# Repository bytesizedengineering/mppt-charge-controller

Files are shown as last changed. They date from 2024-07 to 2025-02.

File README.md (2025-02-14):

## License  
This project is licensed under the GNU General Public License v3.0 - see the [LICENSE](LICENSE) file for details.

# mppt charge controller
BQ 24650 datasheet can be found here https://www.ti.com/general/docs/suppproductinfo.tsp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

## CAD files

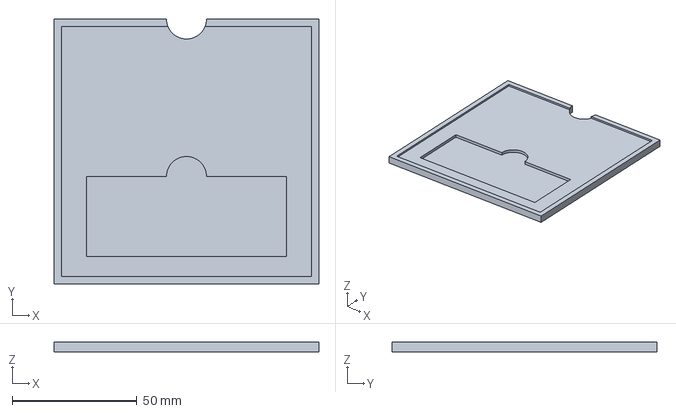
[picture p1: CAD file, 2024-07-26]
Electrical Design/Solder Paste Jig.3mf
106.0 x 106.0 x 4.00 mm

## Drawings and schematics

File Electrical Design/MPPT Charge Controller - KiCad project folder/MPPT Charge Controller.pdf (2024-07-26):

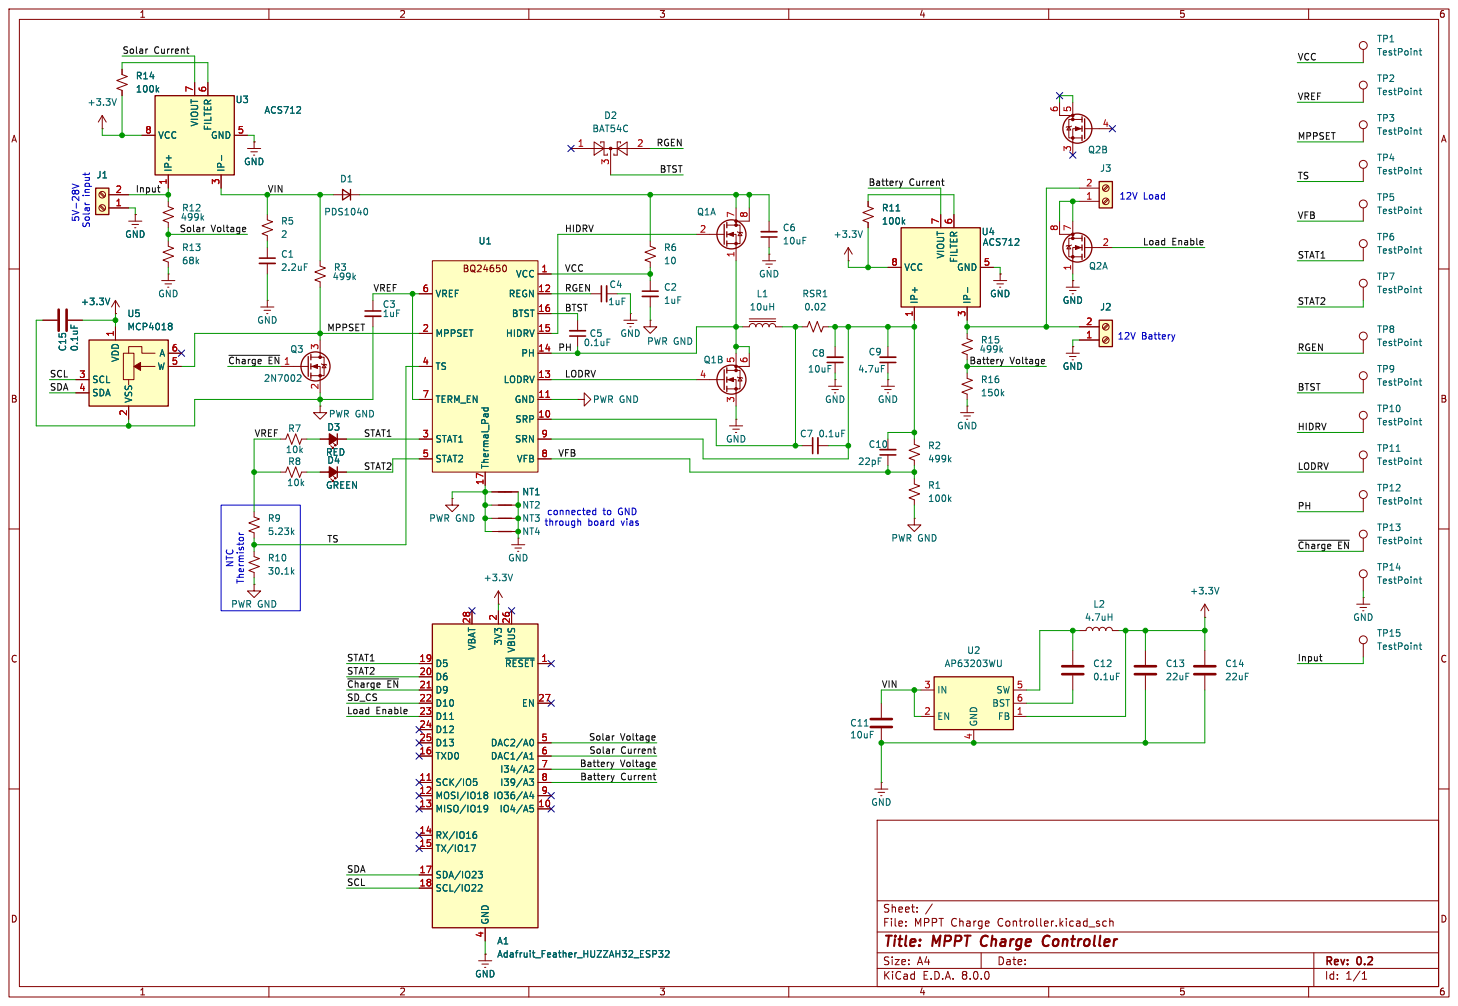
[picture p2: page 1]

STAT1 VCC
~{Charge EN} TSMPPSET BTST PH

7 VCC 8 NT1 U1Thermal_Pad 17 VCC 1 SRP 10 GND 11 REGN 12

TP12 TestPoint TP10 TestPoint TP13 TestPoint TP15 TestPoint D4 GREEN

2 D6 20 D9 21 D10 22 D11 23 D12 24 D13 25 VBUS 26 EN 27 VBAT 28 GND

Battery Current Solar Current STAT1 SD_CS

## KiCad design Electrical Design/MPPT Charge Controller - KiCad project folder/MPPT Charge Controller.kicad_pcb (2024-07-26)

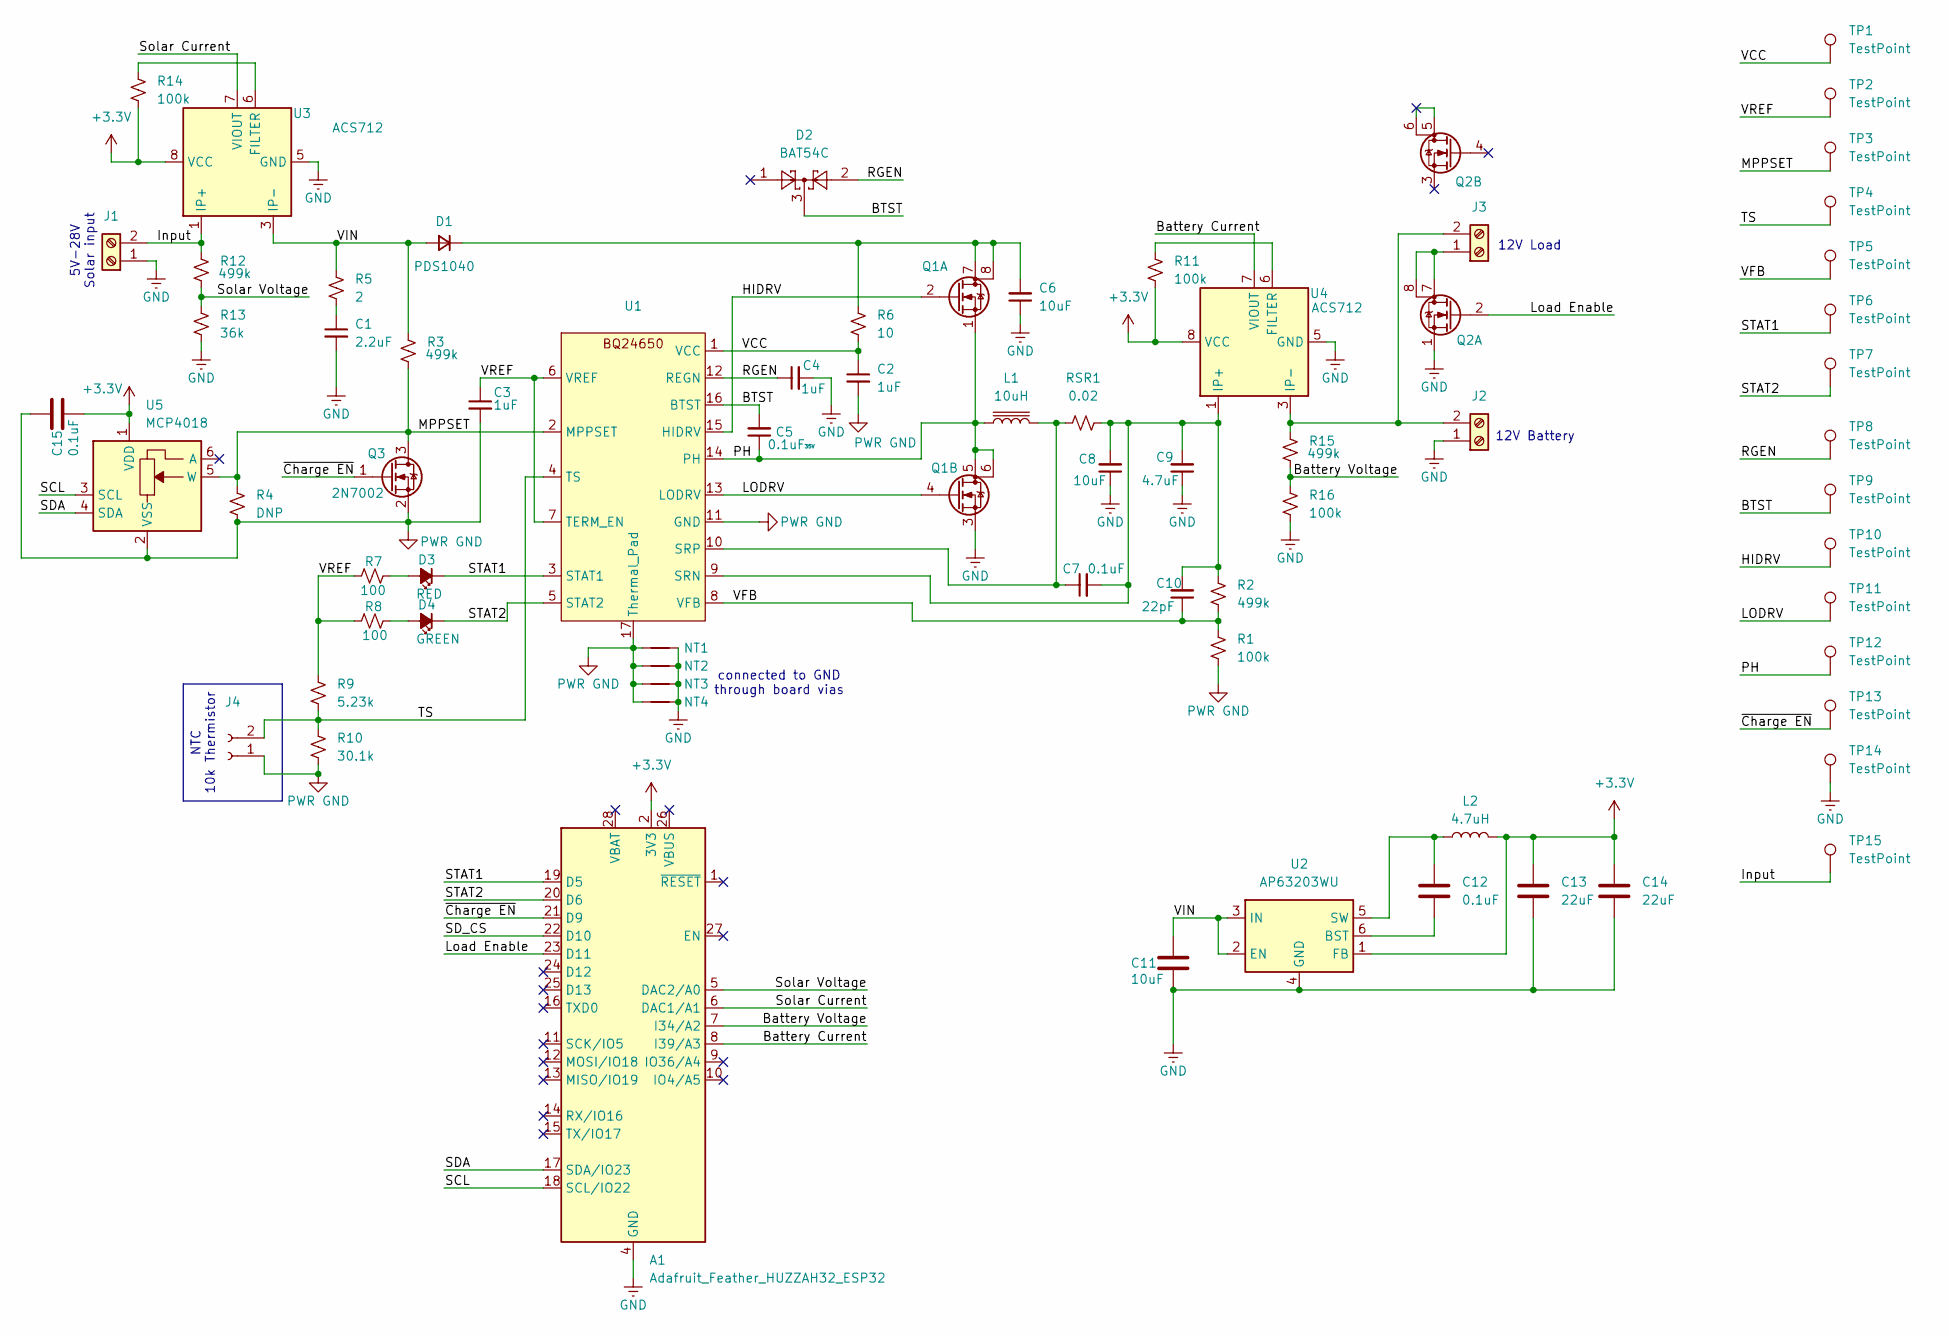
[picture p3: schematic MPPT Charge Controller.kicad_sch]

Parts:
A1: Adafruit_Feather_HUZZAH32_ESP32; Adafruit_Feather
C1: 2.2uF; C_1210_3225Metric
C2, C3, C4: 1uF; C_0603_1608Metric
C5: 0.1uF; C_0603_1608Metric; Voltage Rating 35V
C6, C8: 10uF; C_1206_3216Metric
C7, C12, C15: 0.1uF; C_0603_1608Metric
C9: 4.7uF; C_0805_2012Metric
C10: 22pF; C_0603_1608Metric
C11: 10uF; C_0603_1608Metric
C13, C14: 22uF; C_0603_1608Metric
D1: PDS1040; D_PowerDI-5
D2: BAT54C; SOT-23
D3: RED; LED_0603_1608Metric
D4: GREEN; LED_0603_1608Metric
J1, J2, J3: Conn_01x02_Socket; TerminalBlock_bornier-2_P5.08mm
J4: PinSocket_1x02_P2.54mm_Vertical
L1: 10uH; L_Vishay_6.9x6.5
L2: 4.7uH; L_Vishay_IFSC-1515AH_4x4x1.8mm
NT1, NT2, NT3, NT4: NetTie-2_SMD_Pad0.5mm
Q1, Q2: Q_Dual_NMOS_S1G1S2G2D2D2D1D1; PowerPAK_SO-8_Dual
Q3: 2N7002; SOT-23
R1, R11, R14, R16: 100k; R_0603_1608Metric
R2, R3, R12, R15: 499k; R_0603_1608Metric
R4: DNP; R_0603_1608Metric
R5: 2; R_2512_6332Metric
R6: 10; R_0603_1608Metric
R7, R8: 100; R_0603_1608Metric
R9: 5.23k; R_0603_1608Metric
R10: 30.1k; R_0603_1608Metric
R13: 36k; R_0603_1608Metric
RSR1: 0.02; R_1206_3216Metric
TP1, TP2, TP3, TP4, TP5, TP6, TP7, TP8, TP9, TP10, TP11, TP12, TP13: TestPoint; TestPoint_Pad_D1.0mm
TP14, TP15: TestPoint; TestPoint_Loop_D2.60mm_Drill1.6mm_Beaded
U1: VQFN-16_EP_3.5x3.5_Pitch0.5mm
U2: AP63203WU; TSOT-23-6
U3, U4: ACS712; SOIC-8_3.9x4.9mm_P1.27mm
U5: MCP4018; SOT-363_SC-70-6

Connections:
+3.3V: A1.2 (3V3), C13.1, C14.1, C15.1, L2.2, R11.2, R14.2, U2.1 (FB), U3.8 (VCC), U4.8 (VCC), U5.1 (VDD)
/BTST: C5.2, D2.3, TP9.1, U1.16 (BTST)
/Battery Current: A1.8 (I39/A3), U4.7 (VIOUT)
/Battery Voltage: A1.7 (I34/A2), R15.2, R16.1
/HIDRV: Q1.2 (G), TP10.1, U1.15 (HIDRV)
/Input: J1.2, R12.1, TP15.1, U3.1 (IP+), U3.2 (IP+)
/LODRV: Q1.4 (G), TP11.1, U1.13 (LODRV)
/Load Enable: A1.23 (D11), Q2.2 (G)
/MPPSET: Q3.3 (D), R3.2, R4.1, TP3.1, U1.2 (MPPSET), U5.5 (W)
/PH: C5.1, L1.1, Q1.1 (S), Q1.5 (D), Q1.6 (D), TP12.1, U1.14 (PH)
/RGEN: C4.1, D2.2, TP8.1, U1.12 (REGN)
/SCL: A1.18 (SCL/IO22), U5.3 (SCL)
/SDA: A1.17 (SDA/IO23), U5.4 (SDA)
/SD_CS: A1.22 (D10)
/STAT1: A1.19 (D5), D3.1 (K), TP6.1, U1.3 (STAT1)
/STAT2: A1.20 (D6), D4.1 (K), TP7.1, U1.5 (STAT2)
/Solar Current: A1.6 (DAC1/A1), U3.7 (VIOUT)
/Solar Voltage: A1.5 (DAC2/A0), R12.2, R13.1
/TS: J4.2, R9.2, R10.1, TP4.1, U1.4 (TS)
/VCC: C2.1, R6.2, TP1.1, U1.1 (VCC)
/VFB: C10.1, R1.1, R2.2, TP5.1, U1.8 (VFB)
/VIN: C11.2, D1.2 (A), R3.1, R5.1, U2.2 (EN), U2.3 (IN), U3.3 (IP-), U3.4 (IP-)
/VREF: C3.1, R7.1, R8.1, R9.1, TP2.1, U1.6 (VREF), U1.7 (TERM_EN)
/~Charge EN: A1.21 (D9), Q3.1 (G), TP13.1
GND: A1.4 (GND), C1.2, C4.2, C6.1, C8.1, C9.1, C11.1, C13.2, C14.2, J1.1, J2.1, NT1.2, NT2.2, NT3.2, NT4.2, Q1.3 (S), Q2.1 (S), R13.2, R16.2, TP14.1, U2.4 (GND), U3.5 (GND), U4.5 (GND)
unnamed: C1.1, R5.2
unnamed: C6.2, D1.1 (K), Q1.7 (D), Q1.8 (D), R6.1
unnamed: D3.2 (A), R7.2
unnamed: D4.2 (A), R8.2
unnamed: J2.2, J3.2, R15.1, U4.3 (IP-), U4.4 (IP-)
unnamed: J3.1, Q2.7 (D), Q2.8 (D)
unnamed: C7.2, C8.2, C9.2, C10.2, R2.1, RSR1.1, U1.9 (SRN), U4.1 (IP+), U4.2 (IP+)
unnamed: C7.1, L1.2, RSR1.2, U1.10 (SRP)
unnamed: C12.2, U2.6 (BST)
unnamed: C12.1, L2.1, U2.5 (SW)
unnamed: R14.1, U3.6 (FILTER)
unnamed: R11.1, U4.6 (FILTER)
PWR GND: C2.2, C3.2, C15.2, J4.1, NT1.1, NT2.1, NT3.1, NT4.1, Q3.2 (S), R1.2, R4.2, R10.2, U1.11 (GND), U1.17 (Thermal_Pad), U5.2 (VSS)

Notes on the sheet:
NTC 10k Thermistor
5V-28V Solar input
12V Load
12V Battery
connected to GND through board vias

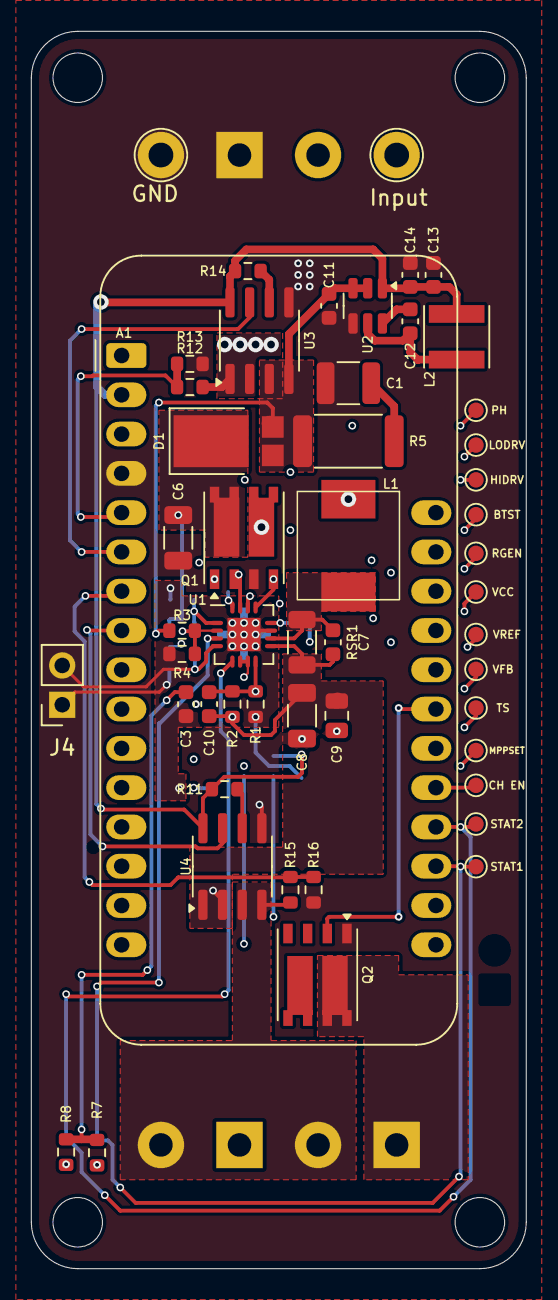
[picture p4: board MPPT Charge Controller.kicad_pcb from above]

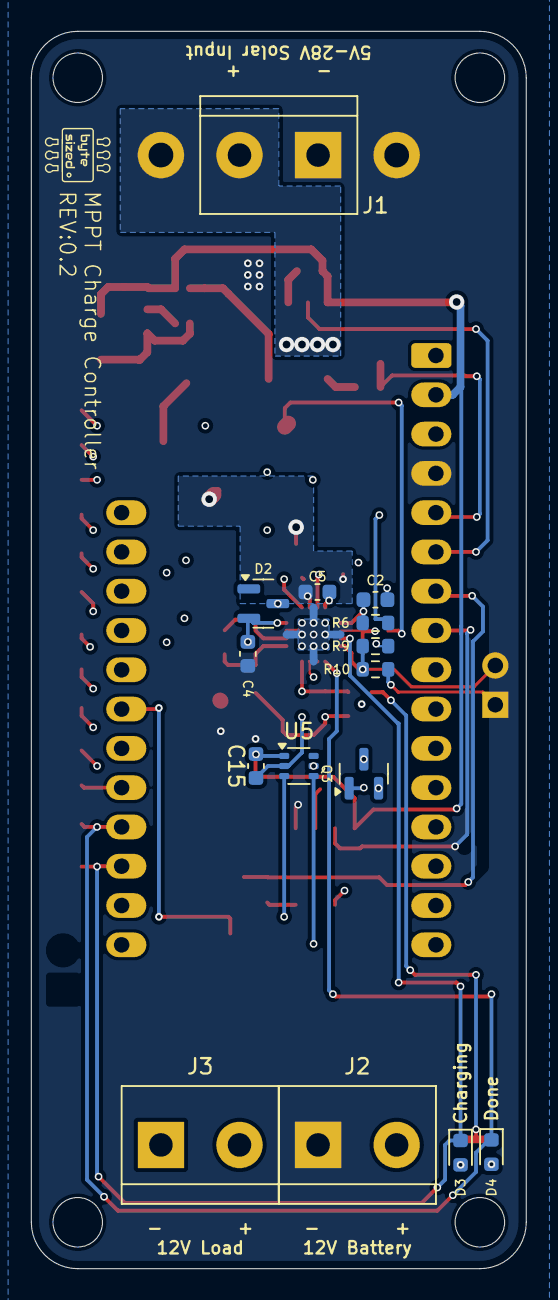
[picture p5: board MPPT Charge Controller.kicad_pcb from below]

Board: 4 copper layers, 32.0 x 80.0 mm, 70 parts (19 on the bottom side), 37 nets.

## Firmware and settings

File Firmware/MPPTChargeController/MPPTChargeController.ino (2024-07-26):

#define LOAD_ENABLE_BUTTON 0 // pulled high by default
#define BATTERY_INFO_BUTTON 1 // pulled low by default
#define SOLAR_INFO_BUTTON 2 // pulled low by default
#define CHARGING_STATUS 5
#define COMPLETE_STATUS 6
#define CHARGE_EN 9
#define LOAD_EN 11
#define SOLAR_VOLTAGE_ADC A0
#define SOLAR_CURRENT_ADC A1
#define BATTERY_VOLTAGE_ADC A2
#define BATTERY_CURRENT_ADC A3
#define MCP4018_ADDRESS 0x2F
#define UPDATE_DATA_INTERVAL 1000

#include <SPI.h>
#include <Wire.h>
#include <Adafruit_GFX.h>    // Core graphics library
#include <Adafruit_ST7789.h> // Hardware-specific library for ST7789
#include <Fonts/FreeSansBold18pt7b.h>
#include <Fonts/FreeSansBold12pt7b.h>


// TFT display and button variables
Adafruit_ST7789 tft = Adafruit_ST7789(TFT_CS, TFT_DC, TFT_RST);
const int displayWidth = 240;
const int displayHeight = 135;
bool solarInfoButtonWasPressed = true, batteryInfoButtonWasPressed = false, loadEnableButtonWasPressed = false, newHeader = true;
unsigned long lastTimeSolarInfoButtonWasPressed = 0, lastTimeBatteryInfoButtonWasPressed = 0, lastTimeLoadEnableButtonWasPressed = 0;
float solarVoltage = 0.0, previousSolarVoltage = 0.0, solarCurrent = 0.0, previousSolarCurrent = 0.0, solarPower = 0.0, previousSolarPower = 0.0;
float batteryVoltage = 0.0, previousBatteryVoltage = 0.0, batteryCurrent = 0.0, previousBatteryCurrent = 0.0, batteryPower = 0.0;
unsigned long lastTimeSolarWasDisplayed = 0, lastTimeBatteryWasDisplayed = 0, lastTimeStatsWerePrinted = 0;
bool increaseVmp = true;

uint8_t potValue = 96;

// Interrupt Service Routines
void IRAM_ATTR loadEnableButton(){
  if(millis() - lastTimeLoadEnableButtonWasPressed > 250){
    lastTimeLoadEnableButtonWasPressed = millis();
    solarInfoButtonWasPressed = false;
    batteryInfoButtonWasPressed = false;
    loadEnableButtonWasPressed = true;
    newHeader = true;
    //Serial.println("load enable button was pressed.");
  }
}
void IRAM_ATTR batteryInfoButton(){
  if(millis() - lastTimeBatteryInfoButtonWasPressed > 250){
    lastTimeBatteryInfoButtonWasPressed = millis();
    solarInfoButtonWasPressed = false;
    batteryInfoButtonWasPressed = true;
    loadEnableButtonWasPressed = false;
    newHeader = true;
    //Serial.println("battery info button was pressed.");
  }
}
void IRAM_ATTR solarInfoButton(){
  if(millis() - lastTimeSolarInfoButtonWasPressed > 250){
    lastTimeSolarInfoButtonWasPressed = millis();
    solarInfoButtonWasPressed = true;
    batteryInfoButtonWasPressed = false;
    loadEnableButtonWasPressed = false;
    newHeader = true;
    //Serial.println("solar info button was pressed.");
  }
}

void setup() {
  Serial.begin(115200);
  Wire.begin();
  // Initialize buttons
  pinMode(LOAD_ENABLE_BUTTON, INPUT_PULLUP);
  pinMode(BATTERY_INFO_BUTTON, INPUT_PULLDOWN);
  pinMode(SOLAR_INFO_BUTTON, INPUT_PULLDOWN);


  attachInterrupt(digitalPinToInterrupt(LOAD_ENABLE_BUTTON), loadEnableButton, FALLING);
  attachInterrupt(digitalPinToInterrupt(BATTERY_INFO_BUTTON), batteryInfoButton, RISING);
  attachInterrupt(digitalPinToInterrupt(SOLAR_INFO_BUTTON), solarInfoButton, RISING);

  // Initialize TFT
  pinMode(TFT_BACKLITE, OUTPUT);
  digitalWrite(TFT_BACKLITE, HIGH);
  pinMode(TFT_I2C_POWER,OUTPUT);
  digitalWrite(TFT_I2C_POWER, HIGH);
  delay(10);
  tft.init(displayHeight, displayWidth); // Init ST7789 240x135
  tft.setRotation(1);
  tft.fillScreen(ST77XX_BLACK);
  //tft.println("Solar MPPT\n Charge Controller "); delay(5000); tft.fillScreen(ST77XX_BLACK);

  pinMode(CHARGING_STATUS, INPUT);
  pinMode(COMPLETE_STATUS, INPUT);
  pinMode(CHARGE_EN, OUTPUT); digitalWrite(CHARGE_EN, LOW);
  pinMode(LOAD_EN, OUTPUT); digitalWrite(LOAD_EN, HIGH);





}

void loop() {
  //read solar voltage and current, and calculate power
  unsigned long sum = 0;
  int sample = 0, numSamples = 100;
  for(int i=0; i<numSamples; i++){
    sample = analogReadMilliVolts(SOLAR_VOLTAGE_ADC);
    sum += sample;
    delay(10);
  }
  float averageSample = sum/numSamples;
  solarVoltage = averageSample*535/36.0/1000.0 + 0.5; // voltage divider resistor values on solar input
  //solarVoltage = previousSolarVoltage*0.99 + solarVoltage*0.01;
  //previousSolarVoltage = solarVoltage;

  sum = 0;
  for(int i=0; i<numSamples; i++){
    sample = analogReadMilliVolts(SOLAR_CURRENT_ADC);
    sum += sample;
    delay(10);
  }
  averageSample = sum/numSamples;
  solarCurrent = (averageSample-1650)/132.0-0.06; // sensitivity is 132mV/A. When no curernt is flowing, sensor outputs 3.3V/2
  //solarCurrent = previousSolarCurrent*0.99 + solarCurrent*0.01;
  //previousSolarCurrent = solarCurrent;

  solarPower = solarVoltage*solarCurrent;
  setVmp();
  previousSolarPower = solarPower;

  //read battery voltage and current and calculate power
  sum = 0;

  batteryVoltage = (analogReadMilliVolts(BATTERY_VOLTAGE_ADC)*599/100.0)/1000.0 + 0.4; // voltage divider resistor values on battery output
  batteryVoltage = previousBatteryVoltage*0.99 + batteryVoltage*0.01;
  previousBatteryVoltage = batteryVoltage;

  batteryCurrent = (analogReadMilliVolts(BATTERY_CURRENT_ADC)*10000/3300.0-5000)/1000.0; // Using a +/-10A current sensor running on 3.3V VCC
  batteryCurrent = previousBatteryCurrent*0.95 + batteryCurrent*0.05;
  previousBatteryCurrent = batteryCurrent;

  batteryPower = batteryVoltage*batteryCurrent;

  float controllerEfficiency = batteryPower/solarPower;


  if(millis() - lastTimeStatsWerePrinted > UPDATE_DATA_INTERVAL){
    lastTimeStatsWerePrinted = millis();
    Serial.print("Solar Input: ");
    Serial.print(solarVoltage); Serial.print("V\t");
    Serial.print(solarCurrent); Serial.print("A\t");
    Serial.print(solarPower); Serial.print("W\t");
    Serial.print("Battery Output: ");
    Serial.print(batteryVoltage); Serial.print("V\t");
    Serial.print(batteryCurrent); Serial.print("A\t");
    Serial.print(batteryPower); Serial.print("W\t");
    Serial.print("Controller Effeciency: "); Serial.print(controllerEfficiency*100); Serial.println("%");


  }

  if(loadEnableButtonWasPressed){
    if(newHeader){
      displayHeader(ST77XX_GREEN, "load enable");
      newHeader = false;
    }
  }
  if(batteryInfoButtonWasPressed){
    if(newHeader){
      displayHeader(ST77XX_RED, "Battery Output");
      newHeader = false;
    }
    if(millis() - lastTimeBatteryWasDisplayed > UPDATE_DATA_INTERVAL){
      lastTimeBatteryWasDisplayed = millis();
      displayData("battery");
    }
  }
  if(solarInfoButtonWasPressed){
    if(newHeader){
      displayHeader(ST77XX_YELLOW, "Solar Input");
      newHeader = false;
    }
    if(millis() - lastTimeSolarWasDisplayed > UPDATE_DATA_INTERVAL){
      lastTimeSolarWasDisplayed = millis();
      displayData("solar");
    }
  }
}

void displayHeader(uint16_t color, String headerText){
  tft.fillRect(0,0,displayWidth,displayHeight/3 - 1,color);
  tft.setTextColor(ST77XX_BLACK); tft.setFont(&FreeSansBold12pt7b);
  tft.setCursor(0, 30);
  tft.print(headerText);
}

void displayData(String source){
  tft.fillRect(0,displayHeight/3,displayWidth,displayHeight*2/3,ST77XX_BLACK);
  tft.setTextColor(ST77XX_WHITE); tft.setFont(&FreeSansBold18pt7b);
  tft.setCursor(0, 75);
  if(source == "solar"){
    tft.print(solarVoltage); tft.print("V  ");
    tft.print(solarCurrent); tft.println("A");
    tft.print(solarPower);   tft.print("W  ");
  }
  else if(source == "battery"){
    tft.print(batteryVoltage); tft.print("V  ");
    tft.print(batteryCurrent); tft.println("A");
    tft.print(batteryPower);   tft.print("W  ");
  }
  else{
    tft.println("invalid data source");
  }
  tft.println(potValue);
}

void setPotentiometerValue(uint8_t value) {
  Wire.beginTransmission(MCP4018_ADDRESS);
  Wire.write(value); //50k digital potentiometer, with 128 taps.
  Wire.endTransmission();
}


void setVmp(){
  // Decreasing the potValue will increase the Vmp.
  // Higher potValue -> lower Vmp. Lower potValue -> higher Vmp.
  // For potValue of 127 (50k Ohms), the Vmp = 13.2V.
  // For potValue of 64 (25k Ohms), Vmp = 25.2V.

  if(solarPower > previousSolarPower){
    if(increaseVmp) potValue--;
    else potValue++;
  }
  else{
    if(increaseVmp){
      increaseVmp = false;
      potValue++;
    }
    else{
      increaseVmp = true;
      potValue--;
    }
  }
  potValue = constrain(potValue, 64, 127); // potValues less than 64 continue to increase Vmp and are unusable for this design. For example a potValue of 1 (391 Ohms), the Vmp would be 1,536.6V
  setPotentiometerValue(potValue);
}

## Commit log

2024-04-19 Created KiCad project
    [MPPT Charge Controller.kicad_pcb, MPPT Charge Controller.kicad_sch]
2024-05-01 Created BQ24650 symbol and footprint
    [MPPT Charge Controller.kicad_pcb, MPPT Charge Controller.kicad_sch]
2024-05-09 Added circuitry to schematic
    [MPPT Charge Controller.kicad_sch]
2024-05-28 Rev .01
    [MPPT Charge Controller-B_Cu.gbr, MPPT Charge Controller-B_Fab.gbr, MPPT Charge Controller-B_Mask.gbr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]
2024-07-08 fixed R4 inconsistency
    [BOM.csv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]
2024-07-26 Added battery temp thermistor connector
    Also cleaned up directory and added .gitignore
    [MPPT Charge Controller.kicad_pcb, MPPT Charge Controller.kicad_sch]
2024-07-26 renamed and cleaned up folders
    [BOM.csv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]
